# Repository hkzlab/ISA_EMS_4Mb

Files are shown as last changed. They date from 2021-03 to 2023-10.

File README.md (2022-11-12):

# ISA 4Mb EMS / ROM Adapter

## Introduction

This is a reimplementation of the **lo-tech.co.uk** [2Mb ISA EMS board](https://www.lo-tech.co.uk/wiki/Lo-tech_2MB_EMS_Board) with small changes:

- All components are thru-hole instead of SMD
- Maximum installable memory expanded to 4Mb
- Activity led to indicate when the memory is accessed
- Optional ROM expansion (had some free space on the PCB...)

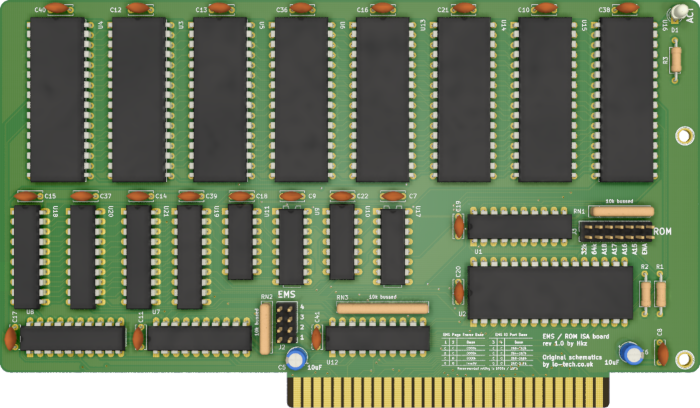
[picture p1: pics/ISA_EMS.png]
Rev. 1.0 PCB


### Disclaimer

I take NO responsibility for what happens if you decide to build and use this card. Your computer might crash, catch fire or be destroyed in other nasty ways.
Also, as this card is mostly based on the work of others, You're encourauged to take what you deem fit from this, and use it in your projects!

Additionally, do **NOT CONTACT lo-tech.co.uk FOR SUPPORT**, while this board is derived from their work, it is not their product, please do not waste their time.

## Configuration

### EMS

To configure the EMS, jumpers on J2 header are used.

Pins 1 and 2 configure the Page Frame base address, while 3 and 4 configure the IO Port base address.

```text

EMS Page Frame Base
 1 | 2 | Base  |
---+---+-------+
 X | X | C000h |
---+---+-------+
   | X | D000h |
---+---+-------+
 X |   | E000h |
---+---+-------+
   |   | Inval |
---+---+-------+

EMS IO Port Base
 3 | 4 |   Base     |
---+---+------------+
 X | X |  260-263h  |
---+---+------------+
   | X |  264-267h  |
---+---+------------+
 X |   |  268-26Bh  |
---+---+------------+
   |   |  26C-26Fh  |
---+---+------------+

```

### ROM

To configure the expansion ROM, jumpers on J3 header are used.

The `ENA` pin will enable the ROM when jumpered.

When `32K` pin is jumpered, only 32Kb of the ROM will be used. The ROM can be made to appear at the following addresses:

```text
       | A18 | A17 | A16 | A15 |
-------+-----+-----+-----+-----+
 A000h |  X  |     |  X  |  X  |
-------+-----+-----+-----+-----+
 A800h |  X  |     |  X  |     | (32K only)
-------+-----+-----+-----+-----+
 B000h |  X  |     |     |  X  |
-------+-----+-----+-----+-----+
 B800h |  X  |     |     |     | (32K only)
-------+-----+-----+-----+-----+
 C000h |     |  X  |  X  |  X  |
-------+-----+-----+-----+-----+
 C800h |     |  X  |  X  |     | (32K only)
-------+-----+-----+-----+-----+
 D000h |     |  X  |     |  X  |
-------+-----+-----+-----+-----+
 D800h |     |  X  |     |     | (32K only)
-------+-----+-----+-----+-----+
 E000h |     |     |  X  |  X  |
-------+-----+-----+-----+-----+
 E800h |     |     |  X  |     | (32K only)
-------+-----+-----+-----+-----+
 F000h |     |     |     |  X  |
-------+-----+-----+-----+-----+
 F800h |     |     |     |     | (32K only)
-------+-----+-----+-----+-----+
```

## Usage

You need a **memory manager** to use this board. The original `LTEMM` driver provided by lo-tech only supports up to 2Mb. You can find a modified version under the `software` directory of this repository that supports up to 4Mb (actually 4080Kb or 255 pages, to support all 256 pages I need to rework the detection logic a bit... will get around to it in the future).

## Bill of Materials

All ICs are in DIP package.

If you don't need the expansion ROM feature, you can omit C19, C20, U1, U2, RN1, R1, R2 and J3.

- U1, U7, U8: 74HCT688
- U2: SST39SF010
- U3, U4, U5, U6, U13, U14. U15, U16: AS6C4008 (You don't need to fill all sockets: fit as much memory as you need starting from socket 1!)
- U11: 74HC04 (HCT is fine too)
- U9: 74HCT139
- U10: 74HCT32
- U12: 74ACT245
- U17: 74HCT138
- U18, U19, U20, U21: 74HCT573
- RN1: res. network, 10k, bussed, 6 pins
- RN2: res. network, 10k, bussed, 5 pins
- RN3: res. network, 10k, bussed, 9 pins.
- R1, R2: 10k resistor
- R3: ~470-1k resistor (depends on the type of LED mounted on D1 and desired brightness)
- D1: 3.0mm or 5.0mm LED
- J2 2x4 2.5mm breakable header
- J3 2x7 2.5mm breakable header
- C5, C6: 10uF / 50v electrolytic caps
- Remaining caps: 22x 100nF, ceramic
- ISA bracket: Keystone 9202, plus screws

## Known Issues

I have received reports of this board being unstable when used with some homebrew PC clones, reports included the Xi8088 and NuXT. I have noted similar issues on a Micro8088. On the other hand, an all-CMOS board was tested fine on multiple AT clones I have.
Replacing the following ICs with ones from the TTL family solved the issue for me and for others: U7, U8, U9, U10, U11, U12.

Note that, for increased stability, I use an ISA terminator with these homebrew computers.

Note that the EEPROM U2 has no buffers on the data output. This can cause instability on loaded/noisy buses. Support for the EEPROM will be removed in newer iterations of this board to produce a smaller variant.

## Credits

- Thanks to [lo-tech.co.uk](https://www.lo-tech.co.uk/) for having published their schematics
- Thanks to [Sergey](http://www.malinov.com/Home/sergeys-projects) for all his projects!

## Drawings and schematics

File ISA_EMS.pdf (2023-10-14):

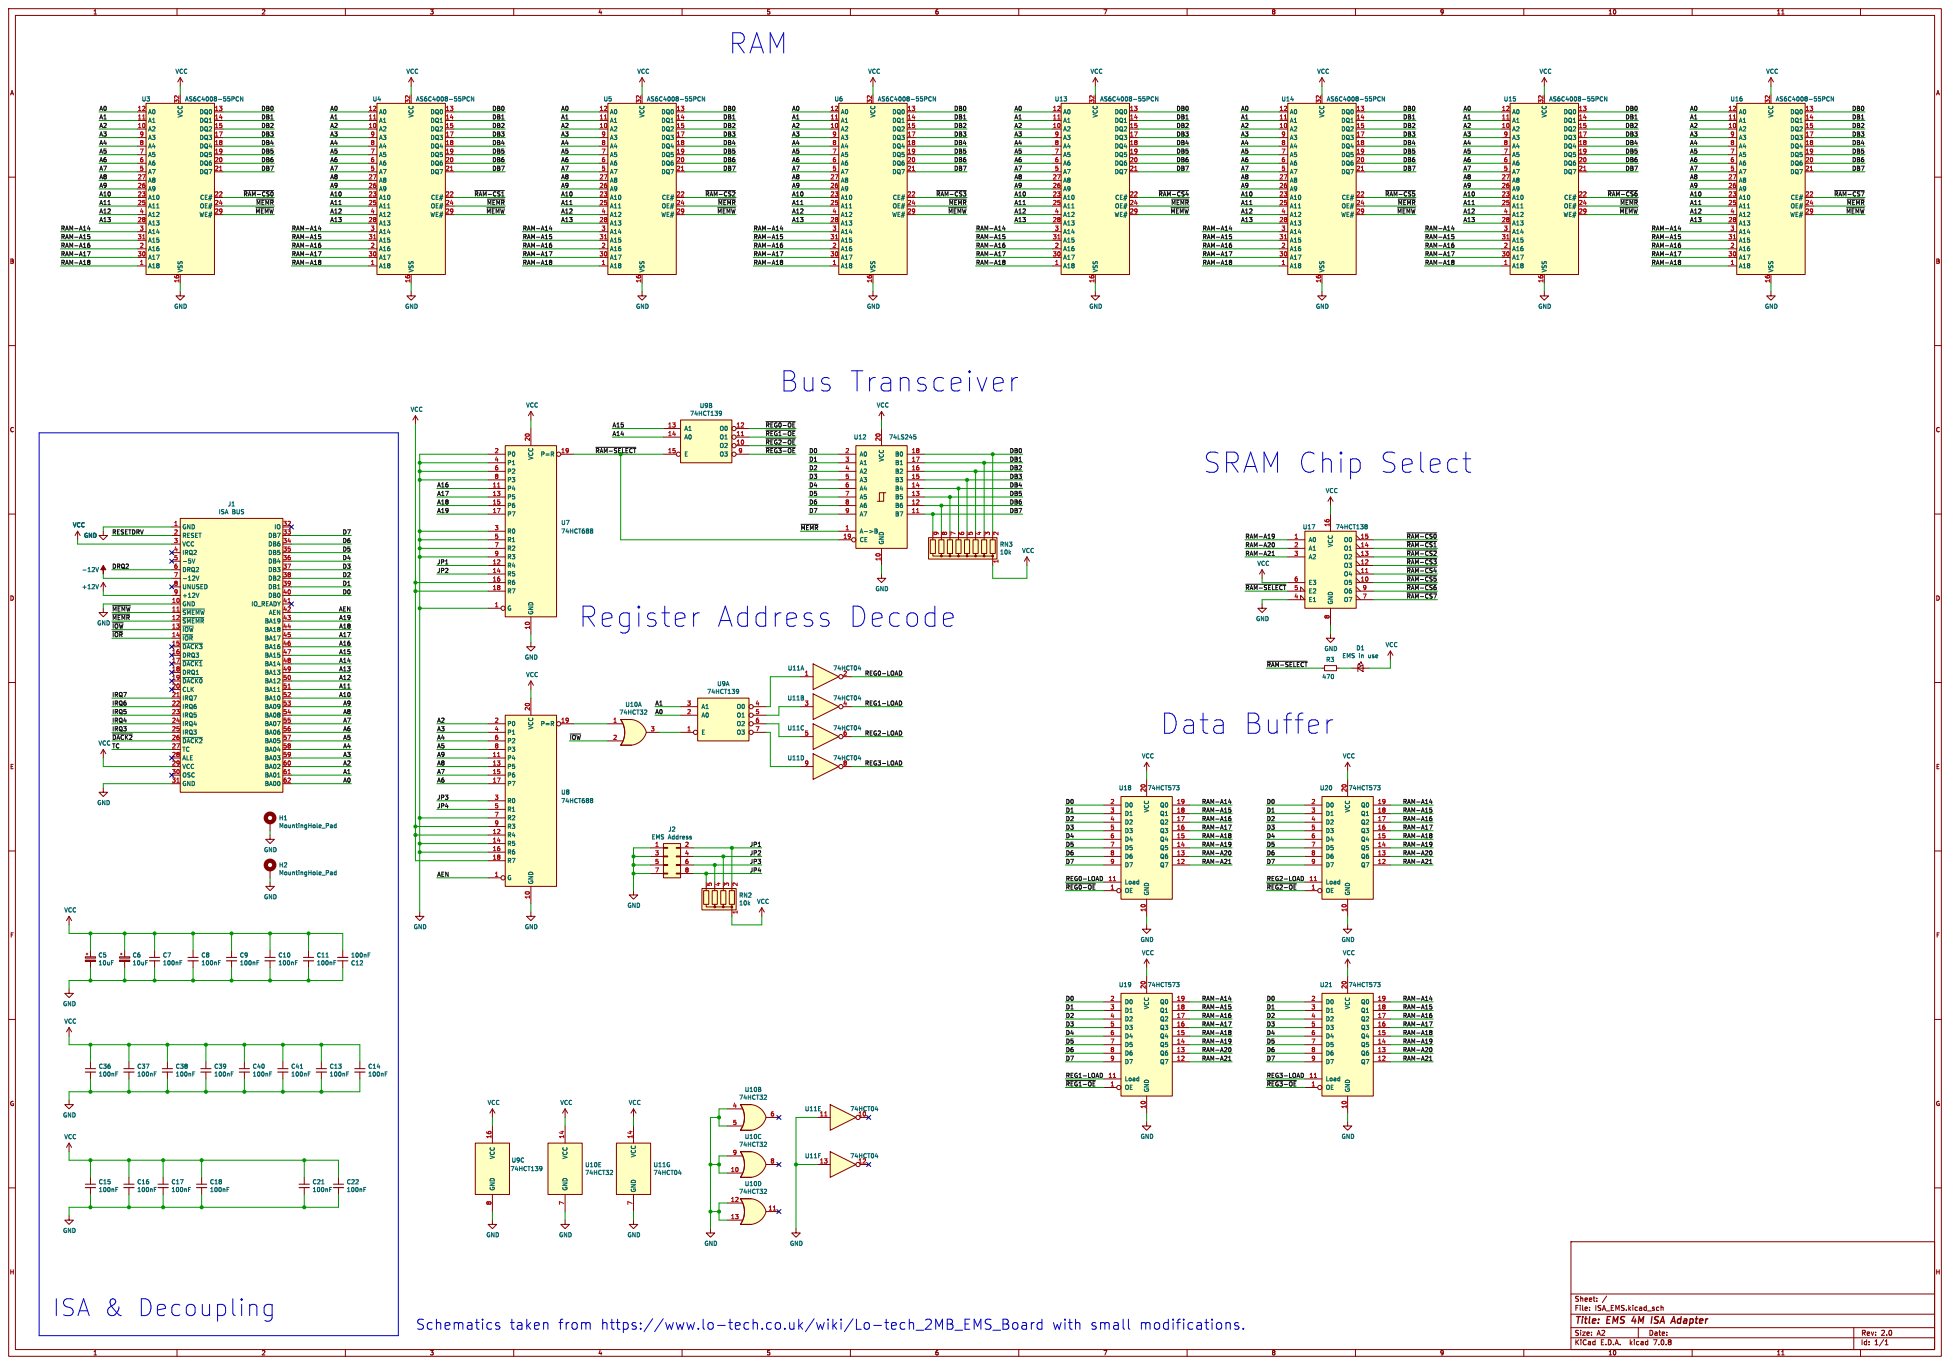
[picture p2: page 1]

RAM-A14 RAM-A15 RAM-A16 RAM-A17 RAM-A18

RAM-A18 RAM-A14 RAM-A15 RAM-A16 RAM-A17

VCC GND 1 GND 10 ~{SMEMW} 11 ~{SMEMR} 12 ~{IOW} 13 ~{IOR} 14 ~{DACK3} 15 DRQ3 16 ~{DACK1} 17 DRQ1 18 ~{DACK0} 19 RESET 2 CLK 20
IRQ6 DRQ2 ~{MEMR} TC

IRQ3 25 ~{DACK2} 26 TC 27 ALE 28 VCC 29 VCC 3 OSC 30 GND 31
IO_READY 41 AEN 42 BA19 43 BA18 44 BA17 45 BA16 46 BA15 47 BA14 48 BA13 49

D1 EMS in use GND

RAM-A21 RAM-A16 RAM-A17 RAM-A18 RAM-A19 RAM-A20 ~{REG3-OE}

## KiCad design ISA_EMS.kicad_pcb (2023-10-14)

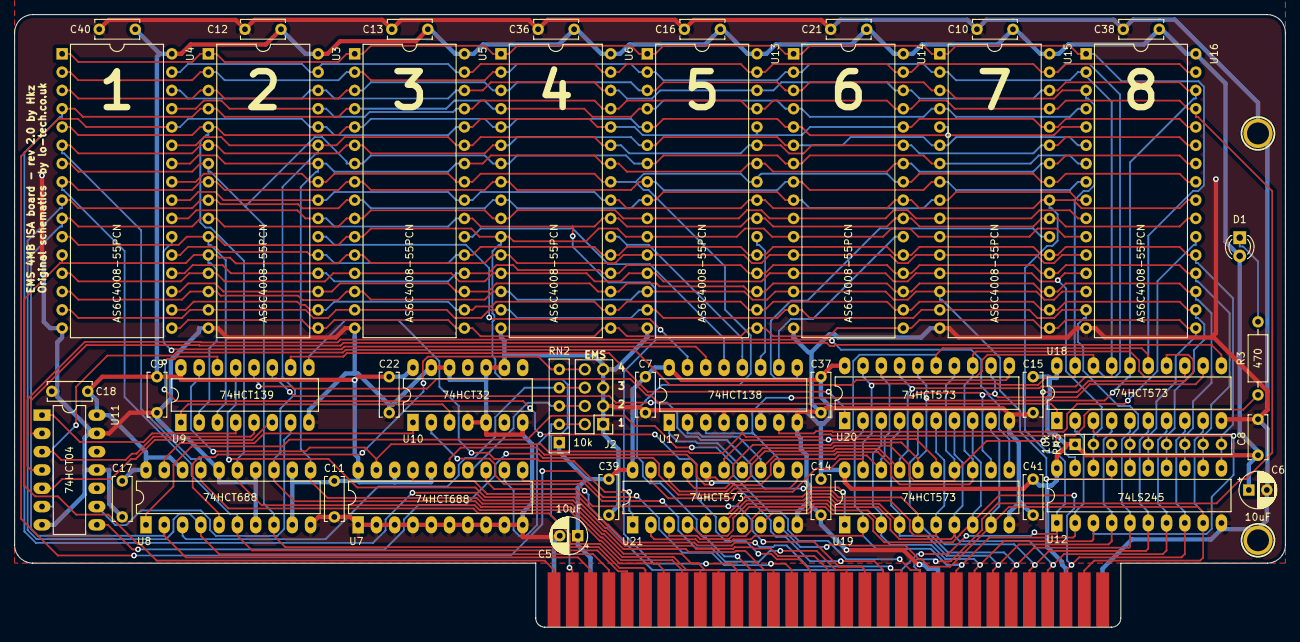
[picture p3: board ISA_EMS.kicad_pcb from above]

Board: 2 copper layers, 176.5 x 85.1 mm, 49 parts (0 on the bottom side), 78 nets.

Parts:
C5, C6: 10uF; CP_Radial_D5.0mm_P2.50mm
C7, C8, C9, C10, C11, C12, C13, C14, C15, C16, C17, C18, C21, C22, C36, C37, C38, C39, C40, C41: 100nF; C_Disc_D6.0mm_W2.5mm_P5.00mm
D1: EMS in use; LED_D3.0mm_Clear
H1, H2: MountingHole_Pad; Hole_3mm
J1: ISA BUS; Conn_Edge_PCB_ISA8
J2: EMS Address; PinHeader_2x04_P2.54mm_Vertical
R3: 470; R_Axial_DIN0207_L6.3mm_D2.5mm_P10.16mm_Horizontal
RN2: 10k; R_Array_SIP5
RN3: 10k; R_Array_SIP9
U3, U4, U5, U6, U13, U14, U15, U16: AS6C4008-55PCN; DIP-32_W15.24mm
U7, U8: 74HCT688; DIP-20_W7.62mm_LongPads
U9: 74HCT139; DIP-16_W7.62mm_LongPads
U10: 74HCT32; DIP-14_W7.62mm_LongPads
U11: 74HCT04; DIP-14_W7.62mm_LongPads
U12: 74LS245; DIP-20_W7.62mm_LongPads
U17: 74HCT138; DIP-16_W7.62mm_LongPads
U18, U19, U20, U21: 74HCT573; DIP-20_W7.62mm_LongPads

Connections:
/A0: J1.62, U3.12, U4.12, U5.12, U6.12, U9.2, U13.12, U14.12, U15.12, U16.12
/A1: J1.61, U3.11, U4.11, U5.11, U6.11, U9.3, U13.11, U14.11, U15.11, U16.11
/A2: J1.60, U3.10, U4.10, U5.10, U6.10, U8.2, U13.10, U14.10, U15.10, U16.10
/A3: J1.59, U3.9, U4.9, U5.9, U6.9, U8.4, U13.9, U14.9, U15.9, U16.9
/A4: J1.58, U3.8, U4.8, U5.8, U6.8, U8.6, U13.8, U14.8, U15.8, U16.8
/A5: J1.57, U3.7, U4.7, U5.7, U6.7, U8.8, U13.7, U14.7, U15.7, U16.7
/A6: J1.56, U3.6, U4.6, U5.6, U6.6, U8.17, U13.6, U14.6, U15.6, U16.6
/A7: J1.55, U3.5, U4.5, U5.5, U6.5, U8.15, U13.5, U14.5, U15.5, U16.5
/A8: J1.54, U3.27, U4.27, U5.27, U6.27, U8.13, U13.27, U14.27, U15.27, U16.27
/A9: J1.53, U3.26, U4.26, U5.26, U6.26, U8.11, U13.26, U14.26, U15.26, U16.26
/A10: J1.52, U3.23, U4.23, U5.23, U6.23, U13.23, U14.23, U15.23, U16.23
/A11: J1.51, U3.25, U4.25, U5.25, U6.25, U13.25, U14.25, U15.25, U16.25
/A12: J1.50, U3.4, U4.4, U5.4, U6.4, U13.4, U14.4, U15.4, U16.4
/A13: J1.49, U3.28, U4.28, U5.28, U6.28, U13.28, U14.28, U15.28, U16.28
/A14: J1.48, U9.14
/A15: J1.47, U9.13
/A16: J1.46, U7.11
/A17: J1.45, U7.13
/A18: J1.44, U7.15
/A19: J1.43, U7.17
/AEN: J1.42, U8.1
/D0: J1.40, U12.2, U18.2, U19.2, U20.2, U21.2
/D1: J1.39, U12.3, U18.3, U19.3, U20.3, U21.3
/D2: J1.38, U12.4, U18.4, U19.4, U20.4, U21.4
/D3: J1.37, U12.5, U18.5, U19.5, U20.5, U21.5
/D4: J1.36, U12.6, U18.6, U19.6, U20.6, U21.6
/D5: J1.35, U12.7, U18.7, U19.7, U20.7, U21.7
/D6: J1.34, U12.8, U18.8, U19.8, U20.8, U21.8
/D7: J1.33, U12.9, U18.9, U19.9, U20.9, U21.9
/DB0: RN3.2, U3.13, U4.13, U5.13, U6.13, U12.18, U13.13, U14.13, U15.13, U16.13
/DB1: RN3.3, U3.14, U4.14, U5.14, U6.14, U12.17, U13.14, U14.14, U15.14, U16.14
/DB2: RN3.4, U3.15, U4.15, U5.15, U6.15, U12.16, U13.15, U14.15, U15.15, U16.15
/DB3: RN3.5, U3.17, U4.17, U5.17, U6.17, U12.15, U13.17, U14.17, U15.17, U16.17
/DB4: RN3.6, U3.18, U4.18, U5.18, U6.18, U12.14, U13.18, U14.18, U15.18, U16.18
/DB5: RN3.7, U3.19, U4.19, U5.19, U6.19, U12.13, U13.19, U14.19, U15.19, U16.19
/DB6: RN3.8, U3.20, U4.20, U5.20, U6.20, U12.12, U13.20, U14.20, U15.20, U16.20
/DB7: RN3.9, U3.21, U4.21, U5.21, U6.21, U12.11, U13.21, U14.21, U15.21, U16.21
/JP1: J2.2, RN2.2, U7.12
/JP2: J2.4, RN2.3, U7.14
/JP3: J2.6, RN2.4, U8.3
/JP4: J2.8, RN2.5, U8.5
/RAM-A14: U3.3, U4.3, U5.3, U6.3, U13.3, U14.3, U15.3, U16.3, U18.19, U19.19, U20.19, U21.19
/RAM-A15: U3.31, U4.31, U5.31, U6.31, U13.31, U14.31, U15.31, U16.31, U18.18, U19.18, U20.18, U21.18
/RAM-A16: U3.2, U4.2, U5.2, U6.2, U13.2, U14.2, U15.2, U16.2, U18.17, U19.17, U20.17, U21.17
/RAM-A17: U3.30, U4.30, U5.30, U6.30, U13.30, U14.30, U15.30, U16.30, U18.16, U19.16, U20.16, U21.16
/RAM-A18: U3.1, U4.1, U5.1, U6.1, U13.1, U14.1, U15.1, U16.1, U18.15, U19.15, U20.15, U21.15
/RAM-A19: U17.1, U18.14, U19.14, U20.14, U21.14
/RAM-A20: U17.2, U18.13, U19.13, U20.13, U21.13
/RAM-A21: U17.3, U18.12, U19.12, U20.12, U21.12
/REG0-LOAD: U11.2, U18.11
/REG1-LOAD: U11.4, U19.11
/REG2-LOAD: U11.6, U20.11
/REG3-LOAD: U11.8, U21.11
/~IOW: J1.13, U10.2
/~MEMR: J1.12, U3.24, U4.24, U5.24, U6.24, U12.1, U13.24, U14.24, U15.24, U16.24
/~MEMW: J1.11, U3.29, U4.29, U5.29, U6.29, U13.29, U14.29, U15.29, U16.29
/~RAM-CS0: U3.22, U17.15
/~RAM-CS1: U4.22, U17.14
/~RAM-CS2: U5.22, U17.13
/~RAM-CS3: U6.22, U17.12
/~RAM-CS4: U13.22, U17.11
/~RAM-CS5: U14.22, U17.10
/~RAM-CS6: U15.22, U17.9
/~RAM-CS7: U16.22, U17.7
/~RAM-SELECT: R3.1, U7.19, U9.15, U12.19, U17.5
/~REG0-OE: U9.12, U18.1
/~REG1-OE: U9.11, U19.1
/~REG2-OE: U9.10, U20.1
/~REG3-OE: U9.9, U21.1
GND: C5.2, C6.2, C7.2, C8.2, C9.2, C10.2, C11.2, C12.1, C13.2, C14.2, C15.2, C16.2, C17.2, C18.2, C21.2, C22.2, C36.2, C37.2, C38.2, C39.2, C40.2, C41.2, H1.1, H2.1, J1.1, J1.10, J1.31, J2.1, J2.3, J2.5, J2.7, U3.16, U4.16, U5.16, U6.16, U7.1, U7.2, U7.3, U7.4, U7.5, U7.6, U7.7, U7.8, U7.9, U7.10, U8.7, U8.10, U8.14, U8.16, U9.8, U10.4, U10.5, U10.7, U10.9, U10.10, U10.12, U10.13, U11.7, U11.11, U11.13, U12.10, U13.16, U14.16, U15.16, U16.16, U17.4, U17.8, U18.10, U19.10, U20.10, U21.10
unnamed: D1.1, R3.2
unnamed: U8.19, U10.1
unnamed: U9.1, U10.3
unnamed: U9.4, U11.1
unnamed: U9.5, U11.3
unnamed: U9.6, U11.5
unnamed: U9.7, U11.9
VCC: C5.1, C6.1, C7.1, C8.1, C9.1, C10.1, C11.1, C12.2, C13.1, C14.1, C15.1, C16.1, C17.1, C18.1, C21.1, C22.1, C36.1, C37.1, C38.1, C39.1, C40.1, C41.1, D1.2, J1.3, J1.29, RN2.1, RN3.1, U3.32, U4.32, U5.32, U6.32, U7.16, U7.18, U7.20, U8.9, U8.12, U8.18, U8.20, U9.16, U10.14, U11.14, U12.20, U13.32, U14.32, U15.32, U16.32, U17.6, U17.16, U18.20, U19.20, U20.20, U21.20

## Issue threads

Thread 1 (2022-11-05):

Is U17 74HCT139 or 74HCT138?

A-Small-Mice, 2022-11-05:
U17 is 74HCT139 In the BoM, but 74HCT138 On the PCB.

Which one is correct?

hkzlab, 2022-11-05:
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
I can't find the '139 on the schematic, on the drawing of the pcb or on an actual board.
Where have you seen it?

Correct one is '138 btw.

hkzlab, 2022-11-05:
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
Ah I read the original comment where it said that the '139 was on the board. Was perplexed not to find it on my boards.

Correct chip is the '138. I will update the BoM.

hkzlab, 2022-11-05:
you can generally trust the board itself more, unless I make a special note on the README regarding a bug.
I usually write the BoMs as a last thing and half-asleep...
Fixed. Closing.

A-Small-Mice, 2022-11-05:
Thank you very much, hkzlab.

Closed 2022-11-05.

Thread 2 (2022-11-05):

EMS parity errors and wrong memory size

A-Small-Mice, 2022-11-05:
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

I made it by myself and installed it on my motherboard.
It has 8 RAM chips.

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

I expected 255 pages, but I got 253 and 254.

The number displayed changes slightly(253~255) every time I boot my computer.

I also conducted EMS memory tests through Checkit.
Checkit indicated that there was a parity error.

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

Finally, there is a problem that the LED is not lit.
I replaced the LED with a new one, but there was no change.

What did I do wrong? I'd appreciate it if you let me know.

hkzlab, 2022-11-05:
Of course I cannot tell You what You did wrong, but I can point out a few things.

First of all, keep in mind the following: as I say on my github bio, I don't offer support, this is not my job.
Second: there is always the chance you got a defective PCB printed out.
Third: I have built 4 of these boards, they're working fine in my 5160 and in 3 ATs. No issues there, but I never tested them on the NuXT.
Fourth: Not using sockets for the logic ICs was a VERY bad idea. This is going to be a pain for you to debug, if it turns out to be a defective IC.

Now, some pointers.
- The logic for the led is VERY simple. The base address is decoded by U7 (a '688), and when it matches with the one you choose via jumper, it brings down a /RAM-SELECT signal that will turn the led on. If the led is not blinking, you have either a bad '688, you are accessing the wrong address, you put the led in reverse or you put too high resistance on R3. When the EMS utility runs by testing memory, it should blink a lot. First of all, fix this
- Parity errors and different pages at each boot, probably tied to the previous point, but could also be bad ram or bad logic chips. Don't worry about this until you fix that led.

From what I see, you set the board to E000h as base address and 260-263h I/O address. Are you positive there is no conflict with any other board or with the UMB memory enabled in the NuXT? The NuXT can have UMB memory at that address that needs disabling.

Have you tried other addresses? Have you tried other I/O ports.

A-Small-Mice, 2022-11-05:
Thank you for your detailed advice. I'll give it a try and tell you the result.

hkzlab, 2022-11-05:
Also, I have the 2Mb version of this board running with the micro8088 by Sergey. Identical circuit but less RAM, and the micro is a close relative of the NuXT, so I'm more convinced that the issue is either a conflict or a bad IC on the card.

A-Small-Mice, 2022-11-08:
Thank you again for your kind and detailed advice..

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
I re-made the EMS card with DIP sockets installed.
I also realized that the LED didn't blink because I put it in reverse. There's no problem right now.

Finally, I tested the logic ICs with my TL866II programmer. All were no problem.

The sad fact is that I still get memory errors. So I thought there might be a problem with AS6C4008, but when I tested all the 40 chips I had, the result was the same. In addition to NuXT, I also tested an XT clone named DTK, but the result were the same.

Now it seems I have only a few options left to try.

1. Replace electrolytic capacitors with new ones
2. Replace HD74ACT245P with LS245 you mentioned
3. Replace SN74HC04N with 74HCT04

hkzlab, 2022-11-08:
Don't put too much trust in tests made with the TL866. If they say an IC is bad it's generally true, but not the reverse. I had chips failing in-circuit when the TL was saying they were fine.

I would start by leaving only 2 ram chips, then swapping around the ICs, starting with the ones you mentioned ('245 and '04), if that does not help, go with the '573s (exchange their places in the sockets).
What happened when you installed only 2 or 4 memory chips? Identical erros?

Could you please take a screenshot of the results of the memory test from CheckIt?
Also, a screenshot of the memory map output of CheckIt could help (without card inserted and EMS driver NOT loaded)

This is a photo of checkit running on one of my ATs with this board in (2mb only installed).
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

hkzlab, 2022-11-08:
This is my memory map, with board inside and EMS driver loaded.
In your case, with board out and no EMS driver, the space should appear as unused/empty.

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

I'm starting to get a little worried about the fact that you mentioned a "parity"error though, because this board has no parity hardware...

A-Small-Mice, 2022-11-08:
I have no '245 and '04 right now, I just ordered these chips, so I'll have to wait until this Thursday to get replacements and test them out.

Even when 2 or 4 ram chips are installed, the problem* still occurs.
(*memory size error and memory parity error)

Once I tried swapping the positions of the '573's, it didn't solve the problem.

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
The picture above is my computer's memory map wtih no EMS card, no EMS driver.

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
The picture above is my computer's memory map wtih the EMS card and the EMS driver.

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

The pictures above are the result of memory test.
I don't know what the repeating number 7 means. 😂

hkzlab, 2022-11-08:
Thanks, so indeed it seems that the address is free!
I've added a few tips for You in the previous comment. Could you also please check the resistor network above the '245? it's bussed right? not a network of separated resistors. Just in case some data lines are shorted together...

A-Small-Mice, 2022-11-08:
Auh... My multimeter's battery is dead.

Instead, I checked the resistor network's spec.
It is A09103JP.

1/8 Watt, Bussed, ±5%

primis, 2022-11-08:
I can replicate this weirdness with pages as well, With three RAM chips (That's all I have at the moment) I'm only seeing 1328K of EMS. Checkit is reporting a *ton* of Bit errors at basically every address line on the EMS addresses

hkzlab, 2022-11-08:
@primis what is the machine you're trying it on? an XT clone, AT clone?
I just disassembled the board I have on another AT to check it, this one with the full 4Mb, to see if I replaced any IC with a different logic family and then forgot, but no. They match what I have on the front page.

I wonder what is happening here. The schematic is the same as the lo-tech EMS board, except with all the ram /CS connected to support the additional ICs

primis, 2022-11-08:
I'm using it on the XI-8088 clone board (www.malinov.com/Home/sergeys-projects/xi-8088) running at standard 4.77MHz with an NEC V20 and 1 wait state. All CMOS chips on my board as well.

hkzlab, 2022-11-08:
I have a xi8088 around, but it's hidden in some box after my last move. The micro8088 should be reachable though. I'll try to dig it up and re-test with an all-cmos board.

hkzlab, 2022-11-08:
hmm, I might have something here.
I took out the Micro8088 (V20 9.5Mhz), which was the base for the NuXT, so it has some similarities, the expansion card I put on there was all-LS chips, so I took it out and put in the all-CMOS one I use in my 286.

First checkin test, all good.
Second checkin test, errors.
Rebooted.
Checkin test, errors again.

So I took the card out, and replaced all the ICs that are connected to the bus with LS ones:
- both the '688 (You can ignore the one near the ROM socket)
- the '139
- the '245
- the '32
- the '04, even though it's not on the bus, mine was an 'HC04 that is not good to feed with an LS.

Tested once, good.
Rebooted and tested once, still good.
Ran 3 tests in a row, good again.
Tested again once, because why not. Good.

So I'd invite You to try by replacing those ICs and see if it makes a difference.
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
hkzlab, 2022-11-10:
@A-Small-Mice Let's see what You get by replacing those too.
If possible, also try to remove extra boards in the machine, and insert one card at a time if You notice the stability improves.

Given that results improve by replacing the CMOS chips with TTL, I'm more and more convinced that the issue is bus noise, as TTL chips are less influenced by it.

On the Micro8088 I initially built, I used 'ACT245 as bus transceivers but had to replace them because they were giving me issues with RS232 expansion cards: I wasn't able to send data above 9600bps.

A-Small-Mice, 2022-11-10:
I also found out that the bus noise has a negative effect on the EMS card's ROM.

I installed IBM ROM BASIC on the ROM storage and tested it.

**Data Curruption**
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

A-Small-Mice, 2022-11-10:
It's useful to some extent.
That's another strong incentive for me to make this card.

A-Small-Mice, 2022-11-12:
This is the last one.

 System                |RAM Size|74LS245|74LS04|74LS32|74LS688 & 74LS139|EMS        Test|ROM Test|
|:------------------:|:---------:|:--------:|:-------:|:-------:|:---------------------:|:-------------:|:---------:|
|NuXT                   |1 MiB      |X           |X          |X         |X                             |Failed            |Failed      |
|NuXT                   |1 MiB      |O          |X          |X          |X                            |Passed           |Failed     |
|NuXT                   |1 MiB      |O          |O          |X         |X                             |Passed           |Failed     |
|NuXT                   |1 MiB      |O          |O          |O         |X                            |Passed           |Failed     |
|NuXT                   |4 MiB      |O          |X          |X          |X                            |Faild               |Failed     |
|NuXT                   |4 MiB      |O          |O         |X          |X                             |Faild              |Failed     |
|NuXT                   |4 MiB      |O          |O         |O          |X                            |Faild              |Failed     |
|DTK Turbo XT      |4 MiB      |O          |O         |O          |X                            |Faild              |N/A        |
|NuXT                   |4 MiB      |O          |O         |O          |O                           |Passed           |Failed      |
|DTK Turbo XT      |4 MiB      |O          |O         |O          |O                           |Passed           |Passed    |

* **X** means the ICs of the original BoM (74ACT245, 74HC04, 74HCT32, 74HCT688, and 74HCT139)
* **O** means LS chips was used.
* Checkit was used for the EMS memory tests.
* The failures in ROM test mean screen glitch.

The complete replacement with the LS chip solved all problems in our memory tests. When using NuXT I still have issues with the ROM test, but this is trivial.

hkzlab, 2022-11-12:
Glad to see your results improve so much :)
Hah, I really should have added a '245 to buffer those data lines from the ROM. If replacing the '688 that acts as the ROM decoder does not help, it might be worth trying a different ROM chip, there isn't much else to do except adding a terminator.

I'll add a warning with your findings to the README, better warn other builders. Leaving this ticket open in case @primis wants to chime in their results.

A-Small-Mice, 2022-11-12:
Finally done!

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

I wish @primis the best of luck, too.

hkzlab, 2022-11-12:
@A-Small-Mice BTW, I think the bracket I used was mouser no.534-9202 / Keystone 9202
Just in case you want a metal one.

A-Small-Mice, 2022-11-12:
Just a question.

Can it be better to replace other remaining chips('573 and '138) with LS ones?

hkzlab, 2022-11-12:
@A-Small-Mice don't think it would bring improvements if the board is already working fine. Those are not in direct communication with the ISA bus.

A-Small-Mice, 2022-12-09:
I got one IBM 5150 this time, and I conducted a test again.

In the previous results, the ROM test always failed, but as I checked now, I think it was a BASIC problem. I put some CGA games in ROM instead of BASIC and it works very well.

hkzlab, 2022-12-09:
Very glad to hear that! Enjoy your board.
Which games did you put in ROM, btw?

A-Small-Mice, 2022-12-09:
A person named Predator99 has created a tool to put CGA games into ROM.  Check out the following link.
https://www.vogons.org/viewtopic.php?f=46&t=67364&p=761478&hilit=ibm%20rom%20basic#p761478

I put Digger in a ROM. It works very well!

Closed 2023-08-05.

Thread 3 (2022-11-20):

Any switch for more page frames than 64 KB?

A-Small-Mice, 2022-11-20:
I know that you modified the LTEMM driver. It seems that the driver has no option for page frame size. It is always fixed at 64 KB, but I sometimes need 128 KB. Is there a way for having 128 KB? If possible, I can use this card for UMB as well.

hkzlab, 2022-11-20:
Not with the card as it is. If you check the schematics, You'll see that the address decoding hardware works with a window size of 64kb.
You'd have to redesign both card and driver.

Closed 2022-11-20.

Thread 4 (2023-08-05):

Files projects from last pcb version.

Kakoryus, 2023-08-05:
The available files in the github have no the ic rom section. Do you make to available the kicad files with the ic-rom section? I like to change litle bit.
Thankyou

hkzlab, 2023-08-05:
Have a look at the history of the repo. Just check out a commit before the removal of the bottom, e.g. 53b305b

Closed 2024-11-19.

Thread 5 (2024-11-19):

Support for 256 page frames using an extra page register

superfury, 2024-11-19:
I've had an idea, looking at the source code of the driver and the original 2MB board schematics:

I've been looking at the Lo-tech EMS driver (in the software directory) for a bit.
I found out something: when it 'disables' a page frame (frame being IObase+0 through IObase+3), it simply writes 0xFF to the port.

Then, looking at the board diagram (https://www.lo-tech.co.uk/w/images/7/73/Lo-tech-2MB-EMS-Board-schematic.png ) I see something interesting:
- The register outputs support full 256 page register values to be decoded onto 8 memory chips, thus 4MB. But, it only connects the first 4, thus setting bit 7 in the registers effectively 'disable' the memory (mapping to chips 4-7, which aren't connected), ignoring reads (floats the bus, thus 'unmapped') and writes don't respond?

Maybe someone could patch the board with an extra storage chip to set *RAM-SELECT (active low) based on *REG0-3OE (which are the inverted frame number bit in the added register to check, basically routed to address the added new register bit from a translation chip simply wire them to the output pins on another 74AC7530 chip like the page registers?), then use it's output bits to make (using a LUT ROM chip, address being the inputs):
Bit looked up(based on REG0-3OE (what window bit to inspect) and the added 74AC7530 chip for the 4MB enabled bit to use) - RAM-A21 - *RAM-SELECT INPUT -> *RAM-SELECT OUTPUT
Default result is 1(unmapped, all other of the 8 cases)
0 - 0 - 0 -> 0 (compatibility, <128 frame indexed)
1 - 1 - 0 -> 0 (4MB page addressed and enabled)
1 - 0 - 0 -> 0 (2MB page addressed and enabled in extended mode)
The only one cases remaining is not adressed and compatibility mode past 128(which is 'unmap page frame').

RAM-SELECT inputted from the 74HCT6880W and outputted to the sRAM CHIP SELECT chip.

So basically, put the new register at base address+4 for example. Then (programming it):
For unmapping: clear bit in register and set bit 7 in the page register (in compatibility mode now, so 2MB EMS compatible, bit 7 unmaps there due to chips 4-7 not being present, so emulate that here. Added bonus: like the original board, memory is unmapped with bit 7 set (since no RAM chips respond)).
For mapping enabled frame: clear bit in register and set page number below 127(compatibility with Lo-tech EMS driver), or set the window's bit (bit 0-3 for frame 0-3)) in register and set a 4MB page frame in the corresponding page register.

Although this is just theoretical. Any thoughts?

Edit: Or maybe more simple translation logic: include the 74AC7530 4-bit outputs in the LUT as well (requiring a 11-bit address for the ROM). So the translation ROM's address pins are connected to:
- RAM-A21 (high bit used)
- *RAM-SELECT input (memory address enable)
- REG0OE (reg0 memory addressed)
- REG10E (reg1 memory addressed)
- REG2OE (reg2 memory addressed)
- REG3OE (reg3 memory addressed)
- 74AC5730 1Q (is REG0-OE enable bit)
- 74AC5730 2Q (is REG1-OE enable bit)
- 74AC5730 3Q (is REG2-OE enable bit)
- 74AC5730 4Q (is REG3-OE enable bit)
And RAM-SELECT can also be connected to the ROM's OE and CS pins to make it output it's result when needed.

Then put the logic results I mentioned into the ROM as a 1-bit output, which is connected to the *RAM-SELECT pin on the sRAM CHIP SELECT chip.

hkzlab, 2024-11-19:
Hello, struggling to understand what the desired end result is here.

The original board does not add the other 4 SRAM ICs, and thus, requesting a page with RAM-A21 high, is effectively pointing into the void for writes.
But, while writes will do nothing, **reads will not float the bus**, at least not the ISA bus: the '245 transceiver will still get enabled, and the pullup resistors behind it will get 0xFF to appear on the bus.
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
This means that the board will not totally disappear from the bus when the pages are "unmapped".

I am genuinely wondering, why is there an interesting in unmapping the pages? Avoid writing garbage to the memory? If a software is doing that because it supports 2MB only, and tries to unmap a card with the full 4MB, it will just end up writing garbage to the upper, unused, 2MBs, leaving the lower ones untouched.

If protection of the content of memory is the desired end result, maybe it would be better implemented with a write protect bit on an additional IO port, disabling writes for upper and lower half of the card?

superfury, 2024-11-19:
Yeah, that's what is happening indeed.

What I mean is an extra 4 bits in the added register at IObase+4, that, like I mentioned, disables the upper 4 chips select pins for each of the window when the bit in said register is cleared. That will have the effect of them not responding, thus pull-up on reads (0xFF) and no action on writes (preventing writing memory), thus retaining the unmapping effect on the selected window.

The pro is that:
- You'll retain compatibility with the 2MB board for unmapping using bit 7 of the register.
- Each window can be individually unmapped (bit 7 (the highest address pin) of the used window register is checked against the active window select 4 pins and others mentioned in the LUT inputs to archieve this. It basically conditionally masks the window global chip enable pin (before the chip is selected at the final chip) based on the selected lower/upper 4 windows being used and the window 4MB enable register).
- Setting the bit in the extra register at IObase+4 (bits 0-3) causes that window to map the high pages normally to 4MB instead of unmapping it, by passing through the global window enable to the 8 chip select lines normally, as in the 2MB card schematics.

hkzlab, 2024-11-19:
Yes, I get what want: selectively disable the upper banks.
What I don't get is the why. What is the use case? Did you find an application that refuses to work if it detects writable ram above a certain page? Or do you have some use for the fact that you need to both write-protect a page and also not be able to read from it?

superfury, 2024-11-19:
The driver can apparently be given the instruction to disable an EMS frame window (evidenced by it's usage of 0xFF (DIS_EMS) in a page register to disable the window). Since bit 7 is driven to float the memory chips on reads and nothing responds on writes (both of the same cause: the chip enable pins aren't connected), that causes reads to return 0xFF(pullup) and writes to not have any effect.

The reset_phys_page and ramchk routines in the LTEMM driver both set this value to the page register.

hkzlab, 2024-11-19:
Now, it's been a few years since I dabbled into this, but, if I remember correctly, this is the reason why I limited the modified driver to 255 pages, so the 256th would be used as scratch and not cause issues when the EMS was "disabled", given that the board is never truly disabled and still occupies the bus.

You sacrifice 16K, you save quite few complexity on the board, plus a small range of I/O ports.

Resetting the latches is a task better suited for the driver, not the circuitry on the card: it would add additional useless complexity: that memory is not meant to be used until the driver is loaded, so it might as well write known values to registers when setting itself up.
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
hkzlab, 2024-11-19:
**Clearing** the bit enables all the RAM banks for said register. **Setting** it will disable the upper banks. So you should call it a 4MB Disable register :) Decoding takes less ICs that way.

Yes, I'm totally ignoring the lower two bits, so the register is mirrored there. There are compromises to be made between number of ICs and precise decoding of the address. Saving 3 I/O ports is not really worth it. Beside, It remains to be seen if the added delay by all that decoding to disable the ram is not going to cause glitches...

I don't see the startup value of those latches in the datasheet. Taking for granted a stable value at powerup is not a good idea.

It's also not important, we're not emulating anything: the board is already using a modified driver and that memory should never be used until the driver is loaded. So the solution here is simple: set the correct value in the registers when you load the driver, depending on the parameters passed to it. If you think about it for a moment, even the original board could start pointing the windows at random locations in the memory, the situation gets rectified when the driver loads.

If the hardware were to operate independently of the OS, it would make sense to go through the effort of properly resetting every latch on the board, but given that it needs initialization... who cares?

hkzlab, 2024-11-20:
You know, after looking at this with a fresh mind, and after having actually redraw the schematic to add this feature... I still think it's a waste of space on the board for little to no gain.

Let me break it down.

The current situation is as follows:
- The board is initialized and handled by a driver. Software should access the additional memory going through the driver, as there is no standardized control interface for EMS.
- Currently, the driver allows 255 pages to be accessed by the software, that's 4080KB, the 256th page is not accessible unless one wants to bypass the driver. We're losing 16KB here.
- When the driver wants to disable a window, it sets it to 0xFF, which is pointing to the 256th, unused page. At that point, writes on that page can happen (from different windows too), but that data cannot be used anyway, so we're not corrupting program memory.
- Unmapping doesn't "free" the address space, as the board is going to respond to reads anyway

With your proposed change:
- We can selectively disable RAM selection for every one of the 4 windows, by setting/clearing a bit in a register and then setting the window to any page > 127 (msb set)
- We can access the whole 256 pages, in case we need to disable access, we need to use the new register
- This requires new decoding circuitry for the additional register (one register, but, more realistically, a space of 4 needs to be occupied, unless one wants to splurge on ICs or go PLD)
- This requires additional decoding circuitry to disable the RAM according to selected window and the new register value

We could simplify this a bit, by making it so that setting a bit in the new register disables the window regardless of the address it is set to. That would save some decoding logic.

But still, it's going to be a bigger, more expensive board, just to save the 16KB.
**This is unless you can come up with some piece of software that actually croaks when the driver points to the unused 16KB instead of disabling the RAM altogether.** That would convince me that the additional space and cost might be worth it.

The updated schematic is already in a branch I pushed and the board just needs to be routed now, if you are convinced otherwise and want to have a go at it though.

superfury, 2025-01-23:
Are there latch chips that can replace the 4MB mapping register (and maybe the 4 window registers as well) that can trigger an all-bits-set when RESET DRV is asserted? That same logic can be used on both it and the window registers to initialize them to 0xFF when that happens, providing full compatibility with the lo-tech EMS board? That also would provide compatibility with BIOSes that might check for UMB memory (since 4MB=0xFF, window=0xFF means it's unmapped if I remember correctly). Or something with a reset pin otherwise (to clear the 4MB  register on RESET DRV)? Don't remember which way the 4MB register worked (toggle on or toggle off), as it's been a while.

hkzlab, 2025-01-23:
Feel free to let me know if you find them, I am not planning further changes to this board, though.

superfury, 2025-01-23:
Did a quick Google search. If using a SN54(LS)175 you can reset using a pin(_CLEAR). It can also supply the output pins both inverted and directly, making it even easier from what I see.

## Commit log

2021-02-24 Import files
    [ISA_EMS.kicad_pcb, ISA_EMS.sch]
2021-02-24 Add first ram CHIP
    [ISA_EMS.sch]
2021-02-24 Add all the necessary RAM chips
    [ISA_EMS.sch]
2021-02-24 Import schematics from lo-tech ems board
    [ISA_EMS.sch]
2021-02-24 Update schematic, draw board
    [ISA_EMS.kicad_pcb, ISA_EMS.sch]
2021-02-24 Routed the board
    [ISA_EMS.kicad_pcb, ISA_EMS.sch]
2021-02-24 Update the silkscreen
    [ISA_EMS.kicad_pcb]
2021-02-24 Added missing cap
    [ISA_EMS.kicad_pcb, ISA_EMS.sch]
2021-02-25 Reorganize board a bit
    [ISA_EMS.kicad_pcb]
2021-02-25 Redoing silkscreen
    [ISA_EMS.kicad_pcb]
2021-02-25 Updated silkscreen
    [ISA_EMS.kicad_pcb]
2021-02-25 Update gerber
2021-02-25 Add notes to schematics
    [ISA_EMS.sch]
2021-03-19 Add BOM
2021-05-06 Removed BOOTROM, make board smaller, reroute
    [ISA_EMS.kicad_pcb, ISA_EMS.sch]
2021-05-06 Reroute some traces
    [ISA_EMS.kicad_pcb]
2021-11-09 Update KiCad URL
2022-11-05 Correct BoM for U17
2023-10-14 Initial import to KiCad 7
    [ISA_EMS.kicad_pcb, ISA_EMS.kicad_sch, ISA_EMS.sch]
